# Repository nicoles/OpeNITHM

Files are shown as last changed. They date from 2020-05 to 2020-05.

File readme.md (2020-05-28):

# OpeNITHM

This repository contails files related to OpeNITHM.

Firmware, schematics, board layout, and CAD files are included in this repo. Please see the CAD directory for the original 3d printed version, or the v2-cad directory for the laser cut version. 

## List of Electronics

OpeNITHM is designed two different processors in mind: the Pro Micro and the Teensy LC.
Based on testing, it seems the Teensy LC is easier to set up and calibrate, but either should work with enough tuning.

### Teensy LC Build

Links are mostly suggestions (except the Teensy, which is only officially available through the PJRC site and authorized resellers).
(VXKZ: I've heard a lot of trouble regarding good quality IR leds and phototransistors, so I've included specific links to the ones I purchased and has worked well for me.)
The links below also assume you want to socket your Teensy and multiplexers for later use. You can solder them directly, if you'd like.
If you are going to solder your sensors directly to the PCB, it is not necessary buy the 0.1" Pin Header, Right Angle. Otherwise, include female 0.1" sockets for your sensors (commonly referred to as Dupont connectors).

| Part | Link | Qty |
| --- | --- |:---:|
| Teensy LC | https://www.pjrc.com/store/teensylc.html | 1 |
| Teensy LC Breakout Board | this Github, Circuit-Teensy folder contains gerbers | 1 |
| 74HC4051 Multiplexer Breaking Board | [Aliexpress][1] | 2 |
| 0.1" Pin Header, 1 row, 40 pos | [Aliexpress (qty 10)][2] | 2 |
| 0.1" Pin Header, Right Angle, 2 row, 16 pos | [LCSC][3] | 2 |
| 0.1" Socket, Straight, 1 row, 14 pos | [LCSC][4] | 2 |
| 0.1" Socket, Straight, 1 row, 5 pos | [LCSC][5] | 2 |
| 0.1" Socket, Straight, 1 row, 11 pos | [LCSC][6] | 2 |
| 0.1" Socket, Straight, 1 row, 8 pos | [LCSC][7] | 2 |
| 51k ohm Resistor, 1/6W or 1/8W | LCSC or Aliexpress | 6 |
| 33 ohm Resistor, 1/4W, 1/6W, or 1/8W | LCSC or Aliexpress | 3 |
| 1m WS2812B RGB 5V LED Strip, 30LED Per Meter | [Aliexpress][8] | 1 |
| IR LED | [Ebay (Qty 100)][9] | 6 |
| IR Phototransistor | [Ebay (Qty 100)][10] | 6 |

[1]: https://www.aliexpress.com/item/32807771098.html
[2]: https://www.aliexpress.com/item/665534073.html
[3]: https://lcsc.com/product-detail/Pin-Header-Female-Header_Changjiang-Connectors-A2541WR-2x8P_C239339.html
[4]: https://lcsc.com/product-detail/Pin-Header-Female-Header_Boom-Precision-Elec-Female-header-2-54-1-14P_C52711.html
[5]: https://lcsc.com/product-detail/Pin-Header-Female-Header_Boom-Precision-Elec-2-54mm-1-5p-Female-header_C50950.html
[6]: https://lcsc.com/product-detail/Pin-Header-Female-Header_Changjiang-Connectors-A2541HWV-11P_C225508.html
[7]: https://lcsc.com/product-detail/Pin-Header-Female-Header_Boom-Precision-Elec-2-54mm-1-8P-Straight-Female-header_C27438.html
[8]: https://www.aliexpress.com/item/2036819167.html
[9]: https://www.ebay.com/itm/100pcs-5mm-IR-Infrared-LED-940nm-Lamp-High-Power-Wide-Angle-Long-Range/251565825589
[10]: https://www.ebay.com/itm/100pcs-5mm-940nm-IR-LED-Infrared-Beams-Detector-Sensor-Black-Phototransistor/251816201528

## Installing on Teensy LC

**NOTE:** This firmware is *only* written to work for the Teensy LC. Do *not* use Teensy 2.0 or Teensy 3.x

Skip this section if you are using a Pro Micro.

Locate your `arduino` folder (usually `C:\Program Files (x86)\arduino`).

#### I have a fresh install of Teensyduino, or have never modified my USB profiles

Copy `Firmware/Teensy/boards.txt` to `arduino\hardware\teensy\avr\` and overwrite the existing.

Copy `Firmware/Teensy/teensy3` to `arduino\hardware\teensy\avr\cores\teensy3` and overwrite any conflicts.

#### I am applying the changes manually

(It is easier to copy and paste from the files in `Firmware/Teensy` instead of through here, the below is just for reference.)

Add `usb_nkro.c` and `usb_nkro.h` to `arduino\hardware\teensy\avr\cores\teensy3`

In `arduino\hardware\teesny\avr\boards.txt` add lines 1175-1179

```c
1175    teensyLC.menu.usb.nkrokeyboard=NKRO Keyboard
1176    teensyLC.menu.usb.nkrokeyboard.build.usbtype=USB_NKRO
1177    teensyLC.menu.usb.nkrokeyboard.fake_serial=teensy_gateway
1178    teensyLC.menu.usb.serialnkrokeyboard=Serial + NKRO Keyboard
1179    teensyLC.menu.usb.serialnkrokeyboard.build.usbtype=USB_SERIAL_NKRO

In `arduino\hardware\teensy\avr\cores\teensy3\WProgram.h` add line 59

```c
58    #include "usb_joystick.h"
59    #include "usb_nkro.h"
60    #include "usb_midi.h"
```

In `arduino\hardware\teensy\avr\cores\teensy3\usb_inst.cpp` add lines 75-77

```c
72    usb_serial_class Serial;
73    #endif
74    
75    #ifdef NKRO_INTERFACE
76    usb_nkro_class Nkro;
77    #endif
78    
79    #else // F_CPU < 20 MHz
```

In `arduino\hardware\teensy\avr\cores\teensy3\usb_dev.h` add lines 93-98

```c
90    extern volatile uint8_t keyboard_leds;
91    #endif
92    
93    #ifdef NKRO_INTERFACE
94    extern uint8_t nkro_report_data[NKRO_SIZE];
95    extern uint8_t nkro_protocol;
96    extern uint8_t nkro_idle_config;
97    extern uint8_t nkro_idle_count;
98    #endif
99    
100   #ifdef MIDI_INTERFACE
```

In `arduino\hardware\teensy\avr\cores\teensy3\usb_desc.h` add lines 868-948

```c
866      #define ENDPOINT15_CONFIG	ENDPOINT_TRANSMIT_ONLY
867    
868    #elif defined(USB_NKRO)
869      #define VENDOR_ID		0x16C0
870      #define PRODUCT_ID		0x04D0
871      #define MANUFACTURER_NAME	{'T','e','e','n','s','y','d','u','i','n','o'}
872      #define MANUFACTURER_NAME_LEN	11
873      #define PRODUCT_NAME		{'N','K','R','O',' ','K','e','y','b','o','a','r','d'}
874     #define PRODUCT_NAME_LEN	13
875      #define EP0_SIZE		64
876      #define NUM_ENDPOINTS         5
877      #define NUM_USB_BUFFERS	14
878      #define NUM_INTERFACE		4
879      #define SEREMU_INTERFACE      1	// Serial emulation
880      #define SEREMU_TX_ENDPOINT    1
881      #define SEREMU_TX_SIZE        64
882      #define SEREMU_TX_INTERVAL    1
883      #define SEREMU_RX_ENDPOINT    2
884      #define SEREMU_RX_SIZE        32
885      #define SEREMU_RX_INTERVAL    2
886      #define KEYBOARD_INTERFACE    0	// Keyboard
887      #define KEYBOARD_ENDPOINT     3
888      #define KEYBOARD_SIZE         8
889      #define KEYBOARD_INTERVAL     1
890      #define KEYMEDIA_INTERFACE    2	// Keyboard Media Keys
891      #define KEYMEDIA_ENDPOINT     4
892      #define KEYMEDIA_SIZE         8
893      #define KEYMEDIA_INTERVAL     4
894      #define NKRO_INTERFACE        3	// NKRO Keyboard
895      #define NKRO_ENDPOINT         5
896      #define NKRO_SIZE             32
897      #define NKRO_REPORT_KEYS		( NKRO_SIZE - 1 )
898      #define NKRO_INTERVAL         1
899      #define ENDPOINT1_CONFIG	ENDPOINT_TRANSMIT_ONLY
900      #define ENDPOINT2_CONFIG	ENDPOINT_RECEIVE_ONLY
901      #define ENDPOINT3_CONFIG	ENDPOINT_TRANSMIT_ONLY
902      #define ENDPOINT4_CONFIG	ENDPOINT_TRANSMIT_ONLY
903      #define ENDPOINT5_CONFIG	ENDPOINT_TRANSMIT_ONLY
904      #define ENDPOINT6_CONFIG	ENDPOINT_TRANSMIT_ONLY
905
906    #elif defined(USB_SERIAL_NKRO)
907      #define VENDOR_ID		0x16C0
908      #define PRODUCT_ID		0x0487
909      #define DEVICE_CLASS		0xEF
910      #define DEVICE_SUBCLASS	0x02
911      #define DEVICE_PROTOCOL	0x01
912      #define MANUFACTURER_NAME	{'T','e','e','n','s','y','d','u','i','n','o'}
913      #define MANUFACTURER_NAME_LEN	11
914      #define PRODUCT_NAME		{'S','e','r','i','a','l','/','N','K','R','O',' ','K','e','y','b','o','a','r','d'}
915      #define PRODUCT_NAME_LEN	20
916      #define EP0_SIZE		64
917      #define NUM_ENDPOINTS         6
918      #define NUM_USB_BUFFERS	14
919      #define NUM_INTERFACE		5
920      #define CDC_IAD_DESCRIPTOR	1
921      #define CDC_STATUS_INTERFACE	0
922      #define CDC_DATA_INTERFACE	1	// Serial
923      #define CDC_ACM_ENDPOINT	2
924      #define CDC_RX_ENDPOINT       3
925      #define CDC_TX_ENDPOINT       4
926      #define CDC_ACM_SIZE          16
927      #define CDC_RX_SIZE           64
928      #define CDC_TX_SIZE           64
929      #define KEYBOARD_INTERFACE    2	// Keyboard
930      #define KEYBOARD_ENDPOINT     1
931      #define KEYBOARD_SIZE         8
932      #define KEYBOARD_INTERVAL     1
933      #define KEYMEDIA_INTERFACE    3	// Keyboard Media Keys
934      #define KEYMEDIA_ENDPOINT     5
935      #define KEYMEDIA_SIZE         8
936      #define KEYMEDIA_INTERVAL     4
937      #define NKRO_INTERFACE        4	// NKRO Keyboard
938      #define NKRO_ENDPOINT         6
939      #define NKRO_SIZE             32
940      #define NKRO_REPORT_KEYS		( NKRO_SIZE - 1 )
941      #define NKRO_INTERVAL         1
942      #define ENDPOINT1_CONFIG	ENDPOINT_TRANSMIT_ONLY
943      #define ENDPOINT2_CONFIG	ENDPOINT_TRANSMIT_ONLY
944      #define ENDPOINT3_CONFIG	ENDPOINT_RECEIVE_ONLY
945      #define ENDPOINT4_CONFIG	ENDPOINT_TRANSMIT_ONLY
946      #define ENDPOINT5_CONFIG	ENDPOINT_TRANSMIT_ONLY
947      #define ENDPOINT6_CONFIG	ENDPOINT_TRANSMIT_ONLY
948    #endif
949    
950    #ifdef USB_DESC_LIST_DEFINE
```

In `arduino\hardware\teensy\avr\cores\teensy3\usb_desc.c` add lines 239-265

```c
236    };
237    #endif
238    
239    #ifdef NKRO_INTERFACE
240    // Via https://dawnmist.dreamwidth.org/1250.html
241    static uint8_t nkro_hid_report_desc[] = {
242            0x05, 0x01, // Usage Page (Generic Desktop),
243            0x09, 0x06, // Usage (Keyboard),
244            0xA1, 0x01, // Collection (Application),
245            // bitmap of modifiers
246            0x75, 0x01, // Report Size (1),
247            0x95, 0x08, // Report Count (8),
248            0x05, 0x07, // Usage Page (Key Codes),
249            0x19, 0xE0, // Usage Minimum (224),
250            0x29, 0xE7, // Usage Maximum (231),
251            0x15, 0x00, // Logical Minimum (0),
252            0x25, 0x01, // Logical Maximum (1),
253            0x81, 0x02, // Input (Data, Variable, Absolute), ;Modifier byte
254            // bitmap of keys
255            0x95, NKRO_REPORT_KEYS*8, // Report Count (),
256            0x75, 0x01, // Report Size (1),
257            0x15, 0x00, // Logical Minimum (0),
258            0x25, 0x01, // Logical Maximum(1),
259            0x05, 0x07, // Usage Page (Key Codes),
260            0x19, 0x00, // Usage Minimum (0),
261            0x29, NKRO_REPORT_KEYS*8-1, // Usage Maximum (),
262            0x81, 0x02, // Input (Data, Variable, Absolute),
263            0xc0 // End Collection
264    };
265    #endif
266    
267    #ifdef JOYSTICK_INTERFACE
268    #if JOYSTICK_SIZE == 12
```

In `arduino\hardware\teensy\avr\cores\teensy3\usb_desc.c` add lines 603-610 and modify line 612

```c
600    #define MULTITOUCH_INTERFACE_DESC_SIZE	0
601    #endif
602    
603    // Via https://dawnmist.dreamwidth.org/1250.html
604    #define NKRO_INTERFACE_DESC_POS	MULTITOUCH_INTERFACE_DESC_POS+MULTITOUCH_INTERFACE_DESC_SIZE
605    #ifdef  NKRO_INTERFACE
606    #define NKRO_INTERFACE_DESC_SIZE	9+9+7
607    #define NKRO_HID_DESC_OFFSET	NKRO_INTERFACE_DESC_POS+9
608    #else
609    #define NKRO_INTERFACE_DESC_SIZE	0
610    #endif
611    
612    #define CONFIG_DESC_SIZE		NKRO_INTERFACE_DESC_POS+NKRO_INTERFACE_DESC_SIZE
613    
614    
615    
616    // **************************************************************
```

In `arduino\hardware\teensy\avr\cores\teensy3\usb_desc.c` add lines 1131-1158

```c
1129   #endif // JOYSTICK_INTERFACE
1130   
1131   #ifdef NKRO_INTERFACE
1132           // interface descriptor, USB spec 9.6.5, page 267-269, Table 9-12
1133           9,                                      // bLength
1134           4,                                      // bDescriptorType
1135           NKRO_INTERFACE,                         // bInterfaceNumber
1136           0,                                      // bAlternateSetting
1137           1,                                      // bNumEndpoints
1138           0x03,                                   // bInterfaceClass (0x03 = HID)
1139           0x00,                                   // bInterfaceSubClass (0x01 = Boot)
1140           0x00,                                   // bInterfaceProtocol (0x01 = Keyboard)
1141           0,                                      // iInterface
1142           // HID interface descriptor, HID 1.11 spec, section 6.2.1
1143           9,                                      // bLength
1144           0x21,                                   // bDescriptorType
1145           0x11, 0x01,                             // bcdHID
1146           0,                                      // bCountryCode
1147           1,                                      // bNumDescriptors
1148           0x22,                                   // bDescriptorType
1149           LSB(sizeof(nkro_hid_report_desc)),      // wDescriptorLength
1150           MSB(sizeof(nkro_hid_report_desc)),
1151           // endpoint descriptor, USB spec 9.6.6, page 269-271, Table 9-13
1152           7,                                      // bLength
1153           5,                                      // bDescriptorType
1154           NKRO_ENDPOINT | 0x80,                   // bEndpointAddress
1155           0x03,                                   // bmAttributes (0x03=intr)
1156           NKRO_SIZE, 0,                           // wMaxPacketSize
1157           NKRO_INTERVAL,                          // bInterval
1158   #endif // NKRO_INTERFACE
1159   
1160   #ifdef MTP_INTERFACE
```

In `arduino\hardware\teensy\avr\cores\teensy3\usb_desc.c` add lines 1602-1605

```c
1600           {0x2100, MULTITOUCH_INTERFACE, config_descriptor+MULTITOUCH_HID_DESC_OFFSET, 9},
1601   #endif
1602   #ifdef NKRO_INTERFACE
1603           {0x2200, NKRO_INTERFACE, nkro_hid_report_desc, sizeof(nkro_hid_report_desc)},
1604           {0x2100, NKRO_INTERFACE, config_descriptor+NKRO_HID_DESC_OFFSET, 9},
1605   #endif
1606   #ifdef MTP_INTERFACE
```

In `arduino\hardware\teensy\avr\boards.txt` add lines 1175-1177
```
1174    teensyLC.menu.usb.flightsim.fake_serial=teensy_gateway
1175    teensyLC.menu.usb.nkrokeyboard=NKRO Keyboard
1176    teensyLC.menu.usb.nkrokeyboard.build.usbtype=USB_NKRO
1177    teensyLC.menu.usb.nkrokeyboard.fake_serial=teensy_gateway
1178    teensyLC.menu.usb.disable=No USB
```

## Configuring the Firmware and IDE

There are a number of options built into the firmware to give you flexibility in your implementation. These are presented as preprocessor defines that can be commented and uncommented to fit.

All user-editable defines are in `Config.h`, see the comments for additional information.

If you are not using either the Pro Micro or Teensy LC boards provided in this repo, it may be necessary to change the definitions of the pins, located in `PinConfig.h`.

If you do not have the FastLED and HID-Project libraries installed, do so though the `Tools->Manage Libraries` menu.

#### Compiling

When using a Pro Micro, select `Arduino/Genuino Micro` from `Tools->Board`.

When using a Teensy LC, select `Teensy LC` from `Tools->Board`, then select `NKRO Keyboard` from `Tools->USB Type` for reactive lights. If you are using serial light updates, select `Serial + NKRO Keyboard`.

Prior to compilation, review the (numerous) options available to the end user in `Config.h`. Comment and uncomment the corresponding options that match your setup.

## Running the Software

#### Configuring

Before use, the controller will need a few parameters set. This can easily be done using the Arduino Serial Monitor.

The exact settings will vary depending on your setup, but I would try these as a starting point:
```
tt50
td50
ta0.05
```

Use the command `g` to confirm your changes registered.

**NOTE:** Serial configuration will not work with serial lights. Disable this feature to allow for configuration.

Per WinEpic:

The touch detection system uses an exponential moving average (EMA) to detect changes in the read value. You need to tune 3 values: deadzone, threshold and alpha.

- **Deadzone** is the maximum value for which a key will be considered "untouched". If the read value ever falls below the deadzone value, the key will return to being untouched. The higher this value, the "harder" you need to push the key before it is considered an input, and the faster it will return to neutral once you start lifting your finger.
- **Threshold** is how large the different between the detected input and the EMA must be for a touch event to occur. It is used for single touches as a way to prevent accidental double inputs, and for double touches to detect them. Increasing it makes the controller less responsive and increases the risk of touches not registering. Decreasing it makes fake inputs more likely, and also makes it harder for the controller to detect multitouch.
- **Alpha** is how much weight the last readout has in the EMA. It is usually very close to 0. If it is too high, inputs won't register as they will be considered too similar to the moving average. If it is too low, the moving average won't update properly causing touches / double touches to not be detected properly.

Threshold and Deadzone values are expressed relative to the calibration baseline. For example, If a key reads 80 untouched and 100 touched, you're gonna want to set your deadzone to something around 15-20. Start with Alpha at 0.001 and slowly go up from there.

You can configure it using commands sent over the serial port. All changes, aside from recalibrating, apply immediately and persist after restarting.

- `tt <value>` changes the threshold.
- `td <value>` changes the deadzone.
- `ta <value>` changes the alpha.
- `tc` forces the controller to recalibrate, if you moved it to a different environment or accidentally touched it during initial calibration.
- `g` prints out the current configuration values.

When tuning, you want to increase alpha until it feels like you're missing inputs, then go back down.

#### Power On

At startup, the LEDs will flash orange 3 times. Do not hold your hands near the touchboard at this time. When the touchboard turns red, calibration begins. After the touchboard turns blue, calibration has finished.

#### Output

By default, the program will run in NKRO Keyboard mode. The specific keyboard keys are set in `USBOutput.cpp`, but are listed here in order of left to right:
```
a z s x d c f v g b h n j m k ,
```
When a second finger touches the pad, the following keys are pressed in order of left to right
```
1 q 2 w 3 e 4 r 5 t 6 y 7 u 8 i
```

By default, the air sensor functions as follows:
- `Home` is held as long as any sensor is triggered and released when there are no sensors triggered.
- `End` is pressed when any motion is detected, as long as the hand was previously in front of the sensors.
- `Page Up` is pressed and released when the sensor detections movement upwards.
- `Page Down` is pressed and released when the sensor detections movement downwards.

If `#define IR_SENSOR_KEY` is uncommented, each air sensor will report back individually. The default binding from bottom to top is:
```
/ . ' ; ] [
```
Per US QWERTY layout.

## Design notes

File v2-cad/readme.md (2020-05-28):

# OpeNITHM

This repository contails files related to the second generation, laser cut case.

## Fasteners

| Part | Link | Qty |
| --- | --- | :---:|
| 25mm M3 Female-Female hex standoffs | [McMaster][1] | 10  |
| 10 or 11mm M3 hex standoffs | | 8 |
| 20mm M5 screw | | 4 |
| M5 hex nuts | | 4 |
| 8mm M3 Black-Oxide Alloy Steel Hex Drive Flat Head Screw | [McMaster][2] | 18 |
| 8mm M3 18-8 Stainless Steel Hex Drive Flat Head Screw | [McMaster][3] | 8 |
| 8mm M3 316 Stainless Steel Button Head Hex Drive Screws | [McMaster][4] | 14 |
| M2.5 hex nuts ||2|
| 25mm M2.5 screw ||2|
| Copper Tape, cut into rectangles 95mm x 26mm | | 16  |

[1]: https://www.mcmaster.com/95947A018
[2]: https://www.mcmaster.com/91294A128
[3]: https://www.mcmaster.com/92125A128
[4]: https://www.mcmaster.com/94500A222

## Electronics changes

As opposed to the original design, this design uses 31 LEDS, 60 per meter spacing (instead of 30). https://www.aliexpress.com/item/2036819167.html

Additionally, this has a center mounted usb-c connector, which is simply https://www.adafruit.com/product/4090, with a small microusb connector soldered to it, connected to the teensy.

## Notes

I've listed the acrylic as either 1.5mm, 3mm, or 5.6mm, but 5mm should work fine.
You may have to adjust for kerf, your laser and my laser act differently.
Red lines are always cut, black is always etch.
If you do not make a shield layer and cover it with foil, you may end up with a ton of noise. Capsense is weird. I'm sorry.

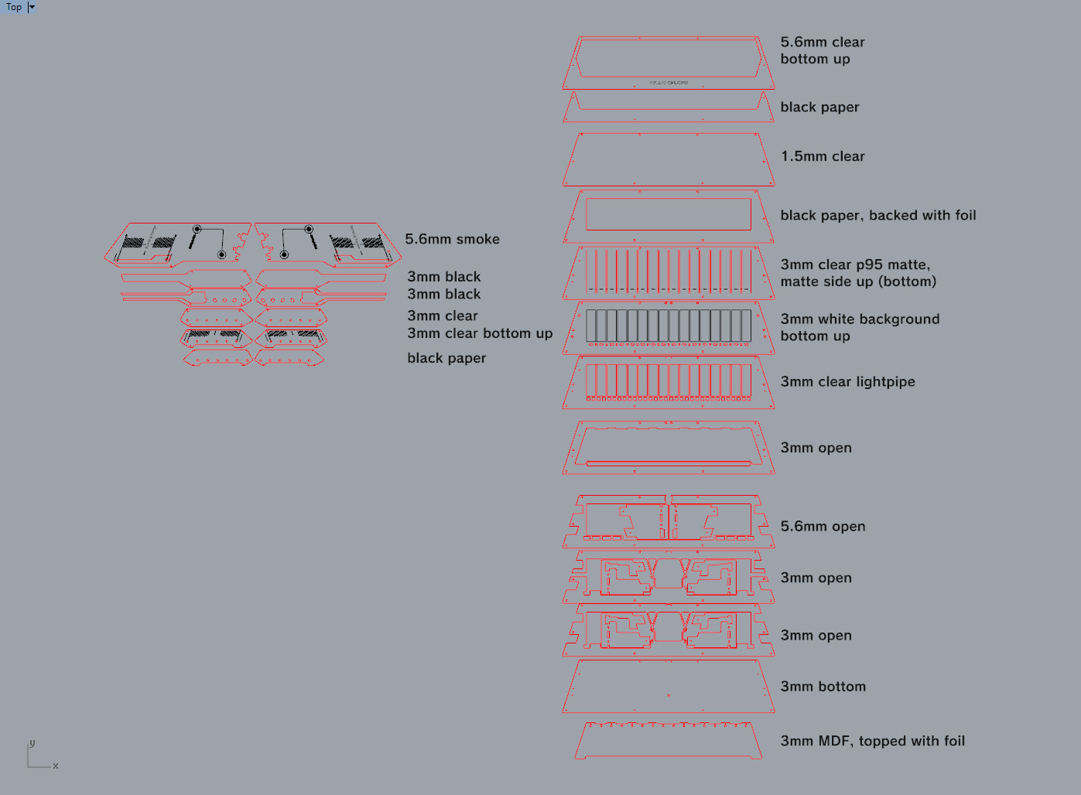
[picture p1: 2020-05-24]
v2-cad/all_layers.jpg

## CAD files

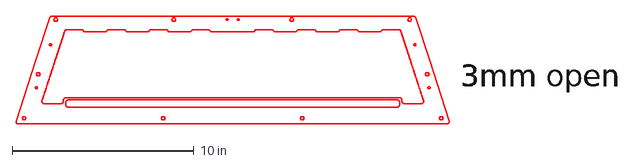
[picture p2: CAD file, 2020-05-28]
v2-cad/shield_3mm_black.dxf
3mm open

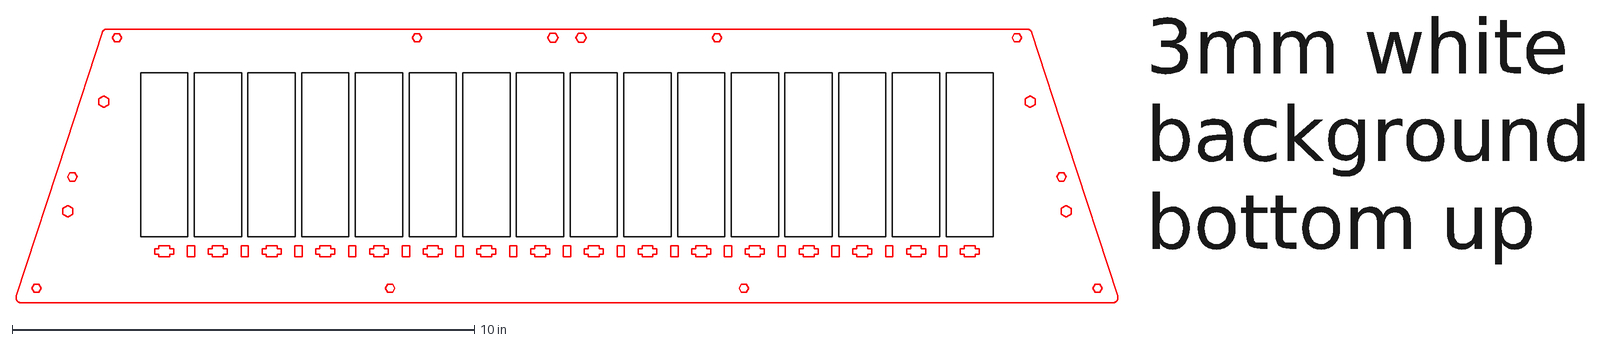
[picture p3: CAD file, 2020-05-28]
v2-cad/key_layer_3mm_white.dxf
3mm white background bottom up

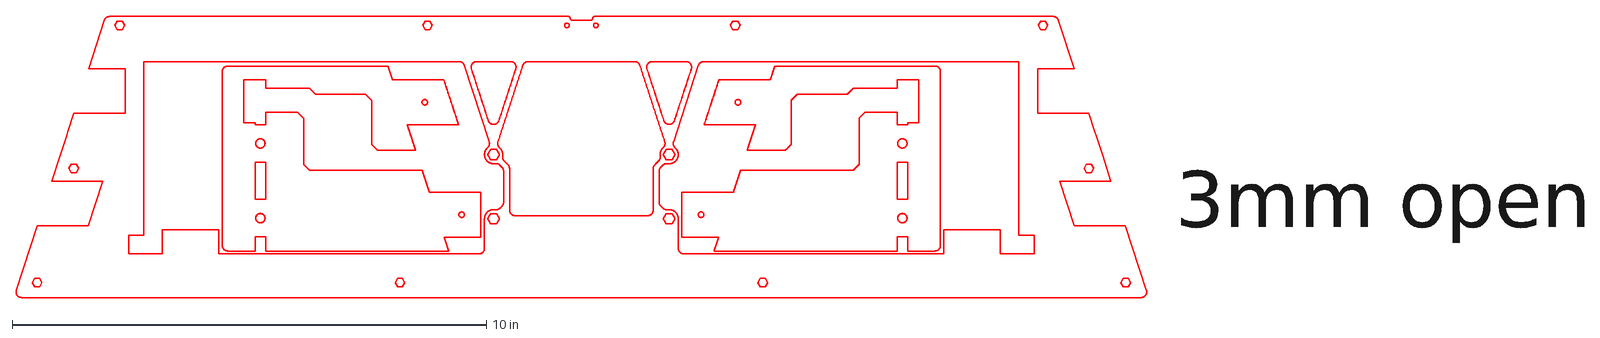
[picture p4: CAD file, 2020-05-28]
v2-cad/interior_case_bottom_3mm_black.dxf
3mm open

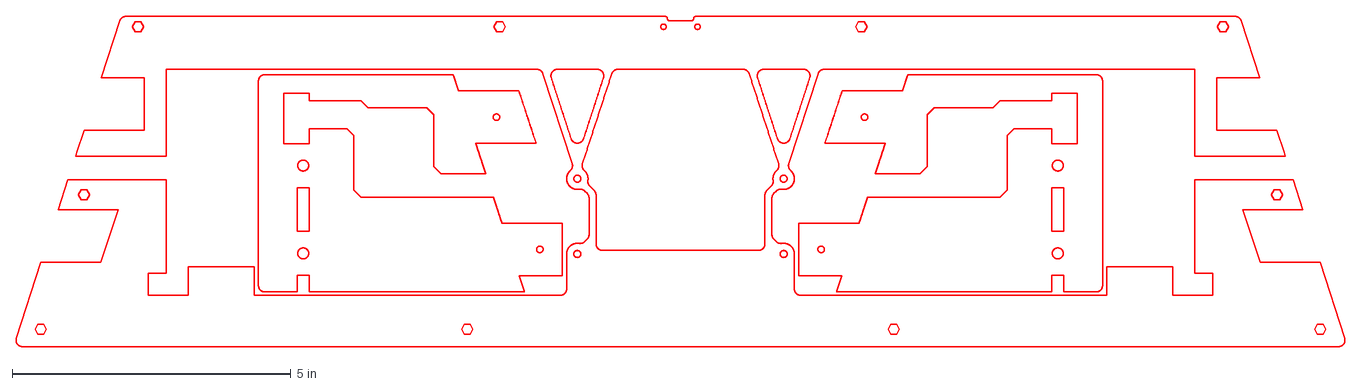
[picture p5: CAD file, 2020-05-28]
v2-cad/interior_case_mid_3mm_black.dxf
23.8 x 5.92 in

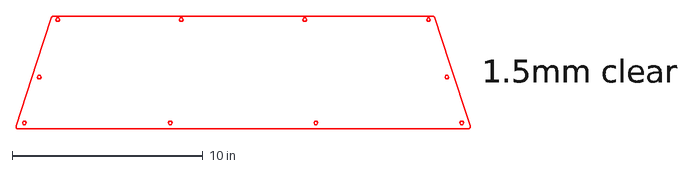
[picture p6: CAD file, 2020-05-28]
v2-cad/thin_surface_layer_1.5mm_clear.dxf
1.5mm clear

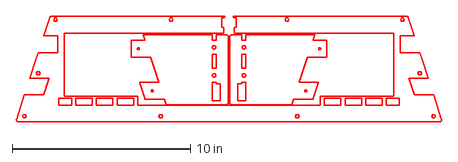
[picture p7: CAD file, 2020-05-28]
v2-cad/interior_case_top_5.6mm_black.dxf
23.8 x 5.92 in

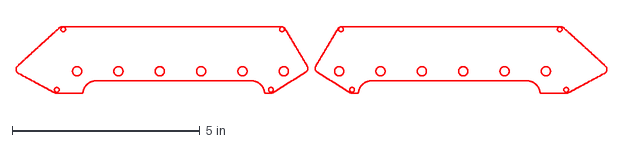
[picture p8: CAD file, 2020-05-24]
v2-cad/side_fronts_black_paper.dxf
15.8 x 1.77 in

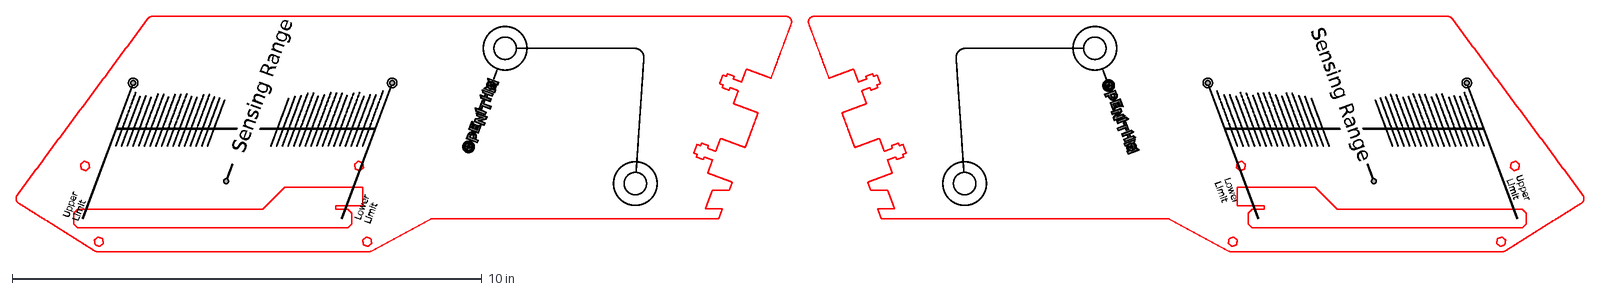
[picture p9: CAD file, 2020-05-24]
v2-cad/side_wings_5.6mm_smoke.dxf
Upper Limit
Sensing Range
Lower Limit

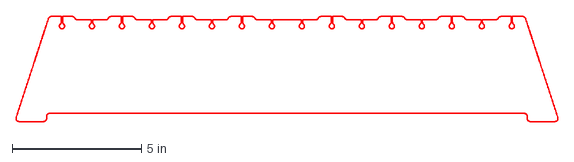
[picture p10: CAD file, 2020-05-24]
v2-cad/shield_interior_3mm_MDF.dxf
21.0 x 4.07 in

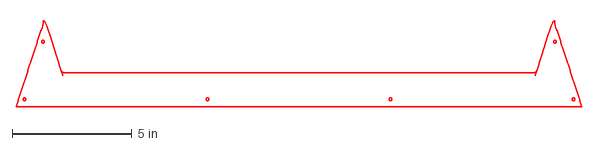
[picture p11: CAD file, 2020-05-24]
v2-cad/top_black_paper.dxf
23.7 x 3.79 in

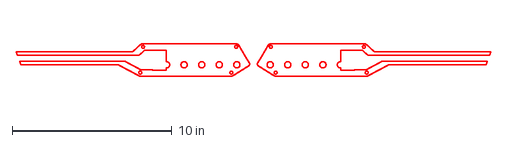
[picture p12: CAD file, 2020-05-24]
v2-cad/side_wire_channel_3mm_black.dxf
29.8 x 2.01 in

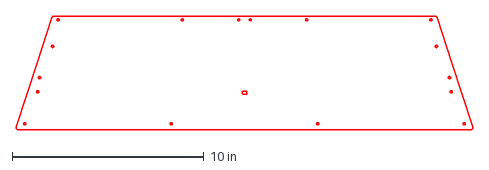
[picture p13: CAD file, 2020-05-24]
v2-cad/bottom_3mm_black.dxf
23.8 x 5.92 in

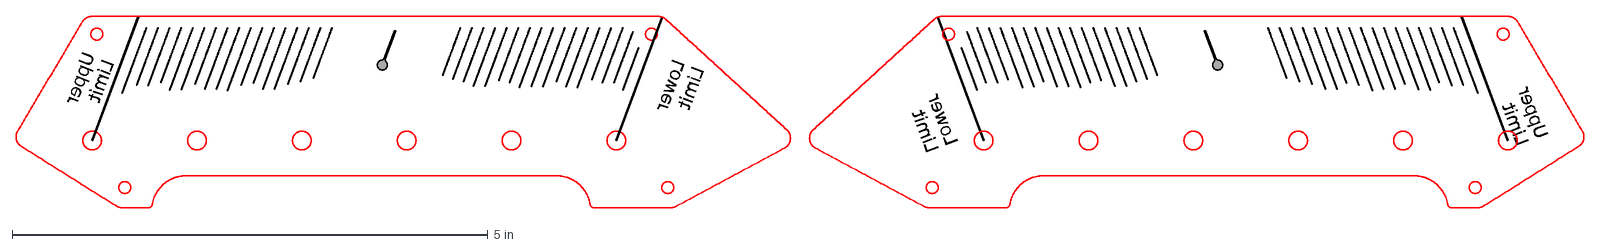
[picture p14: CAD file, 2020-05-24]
v2-cad/side_fronts_3mm_clear.dxf
Upper Limit
Lower Limit

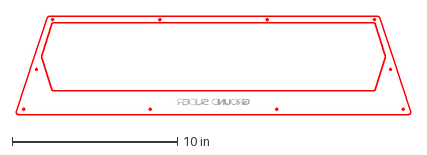
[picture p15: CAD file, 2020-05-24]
v2-cad/top_layer_5.6mm_clear.dxf
23.8 x 5.92 in

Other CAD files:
v2-cad/all_layers.dxf
v2-cad/key_layer_3mm_p95_matte_clear.dxf
v2-cad/light_pipe_3mm_clear.dxf
v2-cad/black_paper_foil_cover.dxf
v2-cad/case-model.obj
v2-cad/openithm_case.3dm
v2-cad/side_backs_3mm_black.dxf
v2-cad/side_spacer_3mm_clear.dxf

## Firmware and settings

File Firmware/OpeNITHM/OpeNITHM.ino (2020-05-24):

#include "PinConfig.h"

#ifdef USB
#include "USBOutput.h"
#else
#include "SerialOutput.h"
#endif

#include "AirSensor.h"
#include "AutoTouchboard.h"
#include "SerialLeds.h"
#include "SerialProcessor.h"
#include "HelperClass.h"
#include <FastLED.h>

SerialProcessor serialProcessor;

KeyState key_states[16];
#ifndef KEY_DIVIDERS
CRGB leds[16];
#else
CRGB leds[31];
#endif
byte serialBuffer[200];
bool updateLeds = false;
bool useSerialLeds = false;
int serialLightsCounter;

CRGB led_on;
CRGB led_off;

float lightIntensity[16];
bool activated = true;

AutoTouchboard *touchboard;
AirSensor *sensor;
Output *output;
SerialLeds *serialLeds;

void initializeController();

void setup() {
  Serial.begin(115200);
  #ifndef KEY_DIVIDERS
  FastLED.addLeds<LED_TYPE, RGBPIN, LED_ORDER>(leds, 16);
  #else
  //Uncomment and tune this value if you're having power issues
  //FastLED.setMaxPowerInVoltsAndMilliamps(5,5OO);
  FastLED.addLeds<LED_TYPE, RGBPIN, LED_ORDER>(leds, 31);
  #endif

  initializeController();
  // Uncomment this to clear EEPROM, flash once, then comment and re-flash
  //for(int i = 0; i < 128; i++) EEPROM.put(i, 0);
}

void initializeController() {
  // Flash LEDs orange 3 times
  for (int i = 0; i < 3; i++)
  {
    for (CRGB& led : leds)
      led = CRGB::Orange;
      
    FastLED.show();
    delay(1000);
    
    for (CRGB& led : leds)
      led = CRGB::Black;
      
    FastLED.show();
    delay(1000);
  }

  // Initialize and calibrate touch sensors
  if (touchboard != NULL) delete touchboard;
  touchboard = new AutoTouchboard();

  // Initialize the serial LED processor
  if (serialLeds != NULL) delete serialLeds;
  serialLeds = new SerialLeds();

  // Initialize the reactive lighting colors, and if they're not in EEPROM, save them
  byte lightsFlag;
  EEPROM.get(67, lightsFlag);

  if (lightsFlag == LIGHTS_FLAG) 
  {
    serialLeds->loadLights();
  } 
  else 
  {
    led_on = CRGB::Purple;
    led_off = CRGB::Yellow;
    serialLeds->saveLights();
  }

  // Initialize air sensor
  if (sensor != NULL) delete sensor;
  sensor = new AirSensor(500, 50);

  // Display the number of air sensors that were calibrated
  for (CRGB& led : leds)
    led = CRGB::Black;
    
  for (int i = 0; i < 6; i++)
  {
    if (sensor->getSensorCalibrated(i))
#ifndef KEY_DIVIDERS
      leds[i] = CRGB::Green;
#else
      leds[i*2] = CRGB::Green;
#endif
    else
#ifndef KEY_DIVIDERS
      leds[i] = CRGB::Red;
#else
      leds[i*2] = CRGB::Red;
#endif
  }
  
  FastLED.show();
  delay(3000);
  serialLightsCounter = 0;

  // Initialize relevant output method / USB or serial
  if (output != NULL) delete output;
  
#ifdef USB
  output = new USBOutput();
#else
  output = new SerialOutput();
#endif
}

void loop() {
  // Check for serial messages
  if (Serial.available() >= 200)
  {
    Serial.readBytes(serialBuffer, 200);
    serialProcessor.processBulk(serialBuffer);
  }
  else 
  {
    serialLightsCounter++;  
  }

  // If currently paused through a config command, do not execute main loop
  if (!activated) 
    return;

  // If we haven't received any serial light updates in 5 seconds, just fallback to reactive lighting
  if (serialLightsCounter > 300) 
    useSerialLeds = false;

  // Scan touch keyboard and update lights
  touchboard->scan();
  int index = 0;
  
  for (int i = 0; i < 16; i++)
  {
#ifndef LED_REVERSE
    index = i;
#else
    index = 15 - i;
#endif

    KeyState keyState = touchboard->update(i);

    // handle changing key colors for non-serial LED updates
    if (!useSerialLeds)
    {
      if (lightIntensity[index] > 0.05f)
        lightIntensity[index] -= 0.05f;
  
      // If the key is currently being held, set its color to the on color
      if (keyState == SINGLE_PRESS || keyState == DOUBLE_PRESS)
      {
        lightIntensity[index] = 1.0f;
#ifndef KEY_DIVIDERS
        leds[index].setRGB(min(led_on.r / 2 + led_on.r / 2 * lightIntensity[index], 255), min(led_on.g / 2 + led_on.g / 2 * lightIntensity[index], 255), min(led_on.b / 2 + led_on.b / 2 * lightIntensity[index], 255));
#else
        leds[index*2].setRGB(min(led_on.r / 2 + led_on.r / 2 * lightIntensity[index], 255), min(led_on.g / 2 + led_on.g / 2 * lightIntensity[index], 255), min(led_on.b / 2 + led_on.b / 2 * lightIntensity[index], 255));
#endif
      }
      else
      {
        // If not, make it the off color
#ifndef KEY_DIVIDERS
        leds[index].setRGB(led_off.r / 2, led_off.g / 2, led_off.b / 2);
#else
        leds[index*2].setRGB(led_off.r / 2, led_off.g / 2, led_off.b / 2);
#endif
      }

#ifdef KEY_DIVIDERS     
      lightIntensity[index] = 1.0f;
      leds[index*2-1].setRGB(min(led_on.r / 2 + led_on.r / 2 * lightIntensity[index], 255), min(led_on.g / 2 + led_on.g / 2 * lightIntensity[index], 255), min(led_on.b / 2 + led_on.b / 2 * lightIntensity[index], 255));
#endif

      updateLeds = true;  
    }
    // handle changing key colors for serial LED updates
    else 
    {
      if (updateLeds)
      {
        RGBLed temp = serialLeds->getKey(i);
#ifndef KEY_DIVIDERS
        leds[index].setRGB(temp.r, temp.g, temp.b);
#else
        leds[index*2].setRGB(temp.r, temp.g, temp.b);
        if (i < 15){
          temp = serialLeds->getDivider(i);
          index = HelperClass::getDividerIndex(i);
          leds[index].setRGB(temp.r, temp.g, temp.b);
        }
#endif
      }
    }

#if !defined(SERIAL_PLOT) && defined(USB)
    if (key_states[i] != keyState)
      output->sendKeyEvent(i, keyState);
#endif

    key_states[i] = keyState;
  }

#ifdef SERIAL_PLOT
  if (PLOT_PIN == -1)
  {
    for (int i = 0; i < 16; i++)
    {
#ifdef SERIAL_RAW_VALUES
      // Print values
      Serial.print(touchboard->getRawValue(i));
#else
      // Print normalized values
      Serial.print(touchboard->getRawValue(i) - touchboard->getNeutralValue(i));
#endif
      Serial.print("\t");
    }
    Serial.println();
  }
  else
  {
    Serial.print(touchboard->getRawValue(PLOT_PIN));
    Serial.println();
  }
#endif

  // Process air sensor hand position
#if !defined(SERIAL_PLOT) && defined(USB)
#ifdef IR_SENSOR_KEY
    output->sendSensor(sensor->getSensorReadings());
#else
    output->sendSensorEvent(sensor->getHandPosition());
#endif
#endif

  // Send update
#if !defined(SERIAL_PLOT) && defined(USB)
  output->sendUpdate();
#endif

  //#if defined(SERIAL_PLOT)
  //  Serial.print("\t");
  //  Serial.println(sensor->getSensorReadings());
  //#endif

  // If the air sensor is calibrated, update lights. The lights will stay red as long as the air sensor is not calibrated.
  if (sensor->isCalibrated() && updateLeds)
  {
    FastLED.show();
    updateLeds = false;
  }
}

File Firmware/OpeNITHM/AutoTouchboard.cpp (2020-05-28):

#include "AutoTouchboard.h"

void AutoTouchboard::scan()
{
  // For each key, set multiplexers and poll both capacitive sensors simultaneously
  for (int i = 0; i < 8; i++)
  {
    digitalWrite(MUX_0, bitRead(i, 0));
    digitalWrite(MUX_1, bitRead(i, 1));
    digitalWrite(MUX_2, bitRead(i, 2));

#ifndef TEENSY
    unsigned int* values = sensor.sense(3);

    // Store the values received from the sensor poll into their respective positions
    key_values[i] = values[0];
    key_values[i + 8] = values[1];
#else
    key_values[i] = touchRead(TOUCH_0);
    key_values[i+8] = touchRead(TOUCH_1);
#endif
  }
}

void AutoTouchboard::loadConfig()
{
  for (int i = 0; i < 16; i++) 
  {
    EEPROM.get(i * 2, single_thresholds[i]);
    EEPROM.get((i * 2) + 32, double_thresholds[i]);
  }
}

void AutoTouchboard::saveConfig()
{
  for (int i = 0; i < 16; i++)
  {
    EEPROM.put(i * 2, single_thresholds[i]);
    EEPROM.put((i * 2) + 32, double_thresholds[i]);
  }

  EEPROM.put(64, (byte) CALIBRATION_FLAG);
}

void AutoTouchboard::calibrateKeys(bool forceCalibrate = false)
{
  // we'll only calibrate if:
  //   * the user is holding the last 4 keys
  //   * the calibration flag is not set in EEPROM
  bool needsCalibration = forceCalibrate;
  
  byte calibrationFlag;
  EEPROM.get(64, calibrationFlag);

  // only check the last 4 keys if we've calibrated at least once
  if (calibrationFlag == CALIBRATION_FLAG) 
  {
    loadConfig();
    
    int touched = 0;
    scan();

    for (int i = 12; i < 16; i++) 
    {
      if (update(i) != UNPRESSED) touched++;
    }

    if (touched == 4) needsCalibration = true;
  }
  else 
  {
    needsCalibration = true;
  }

  if (needsCalibration)
  {
    uint16_t baselines[16];
    
    // Reset calibration data for all keys
    for (int i = 0; i < 16; i++)
    {
      key_values[i] = 0;
      single_thresholds[i] = 0xFFFF;
      double_thresholds[i] = 0xFFFF;
    }

    // Flash every key red a few times so they know to let go of the slider
    for (int i = 0; i < 5; i++) 
    {
      for (int j = 0; j < 16; j++)
      {
#ifndef KEY_DIVIDERS
        leds[j] = CRGB::Red; 
#else
        leds[j*2] = CRGB::Red;
#endif
      }

      FastLED.show();
      delay(500);

      for (int j = 0; j < 16; j++)
      {
#ifndef KEY_DIVIDERS
        leds[j] = CRGB::Purple; 
#else
        leds[j*2] = CRGB::Purple;
#endif
      }

      FastLED.show();
      delay(500);
    }
  
    // Figure out the baselines for each key
    for (int i = 0; i < CALIBRATION_SAMPLES; i++) 
    {
      scan();
    }
  
    // figure out the baseline for each key
    for (int i = 0; i < 16; i++) 
    {
      baselines[i] = key_values[i];
    }
  
    // Iterate over each key and have the user single press to calculate
    // our threshold windows. Since each finger raises the value by roughly
    // the same amount, we have the single double press each key, obtain the
    // average readout, then use the baselines to calculate a window for singles
    // and doubles
    for (int i = 0; i < 16; i++) 
    {
#ifndef KEY_DIVIDERS
        leds[i] = CRGB::Red; 
#else
        leds[i*2] = CRGB::Red;
#endif
      FastLED.show();
  
      // wait until we detect a touch, then start measuring to determine the average
      while (key_values[i] < baselines[i] + CALIBRATION_DETECTION_THRESHOLD) 
      {
        scan();
      }
  
#ifndef KEY_DIVIDERS
        leds[i] = CRGB::Blue; 
#else
        leds[i*2] = CRGB::Blue;
#endif      
      FastLED.show();
      
      for (int j = 0; j < CALIBRATION_SAMPLES; j++) 
      {
        scan();
      }
  
#ifndef KEY_DIVIDERS
        leds[i] = CRGB::Green; 
#else
        leds[i*2] = CRGB::Green;
#endif
      FastLED.show();
  
      uint16_t window = (key_values[i] - baselines[i]) * (sensitivity / 100.0f);
      single_thresholds[i] = baselines[i] + window;
      double_thresholds[i] = baselines[i] + (2 * window);
    }

    saveConfig();
  }
  else 
  {
    // just set the keys green
    for (int i = 0; i < 16; i++) 
    {
#ifndef KEY_DIVIDERS
        leds[i] = CRGB::Green; 
#else
        leds[i*2] = CRGB::Green;
#endif
      FastLED.show();
    }
  }
}

KeyState AutoTouchboard::update(int key)
{
  if (key_values[key] > double_thresholds[key])
    return DOUBLE_PRESS;
  else if (key_values[key] > single_thresholds[key])
    return SINGLE_PRESS;
  else
    return UNPRESSED;
}

uint16_t AutoTouchboard::getRawValue(int key)
{
  return key_values[key];
}

void AutoTouchboard::setSensitivity(uint8_t sensitivity)
{
  this->sensitivity = sensitivity;
  EEPROM.put(65, sensitivity);
}

uint8_t AutoTouchboard::getSensitivity()
{
  return sensitivity;
}

AutoTouchboard::AutoTouchboard()
#ifndef TEENSY
  sensor(CapacitiveSensor(SEND, RECEIVE_1, RECEIVE_2)),
#endif
{
  pinMode(MUX_0, OUTPUT);
  pinMode(MUX_1, OUTPUT);
  pinMode(MUX_2, OUTPUT);

  EEPROM.get(65, sensitivity);
  
  if (sensitivity == 0)
    setSensitivity(DEFAULT_SENSITIVITY);

  calibrateKeys();
}

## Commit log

2020-05-24 add v2 case
    Adding rhino file, all objects as individual dxfs
    [all_layers.dxf, black_paper_foil_cover.dxf, bottom_3mm_black.dxf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]
2020-05-24 Adjusted pcb mount hex sizing
    was off, no idea why
    [all_layers.dxf, interior_case_bottom_3mm_black.dxf, openithm_case.3dm]
2020-05-24 Added initial readme for cad
2020-05-28 Updated standoff to 4.5mm hex
    round drone standoffs arent the right thing, this should be using hex standoffs since you don't see it anyhow.
    [all_layers.dxf, black_paper_foil_cover.dxf, interior_case_bottom_3mm_black.dxf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]
2020-05-28 fixed compile errors
    in trying to make this more presentable i copied and pasted a couple things i shouldn't have. fixed~
    [AutoTouchboard.cpp]
